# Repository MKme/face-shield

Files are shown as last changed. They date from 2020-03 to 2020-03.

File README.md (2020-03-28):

# face-shield
Open Source Face Shield for Covid-19

### ORIGINAL DESIGN Protective Visor by 3DVerkstan 

 https://www.youmagine.com/designs/protective-visor-by-3dverkstan

<p align="center">
<b>IMPORTANT_ I did not design this from scratch- see orginal design above I just need a place to track my versions and modifications to the files. Original .stl files are found above- split version by TekMason below. Hit @erikcederb on twitter and tell him thanks if you use this too. 

Open source Covid-19 face shield for medical and public use (splash shield NOT mask) reference files tips and tricks I find along the way</b><br>

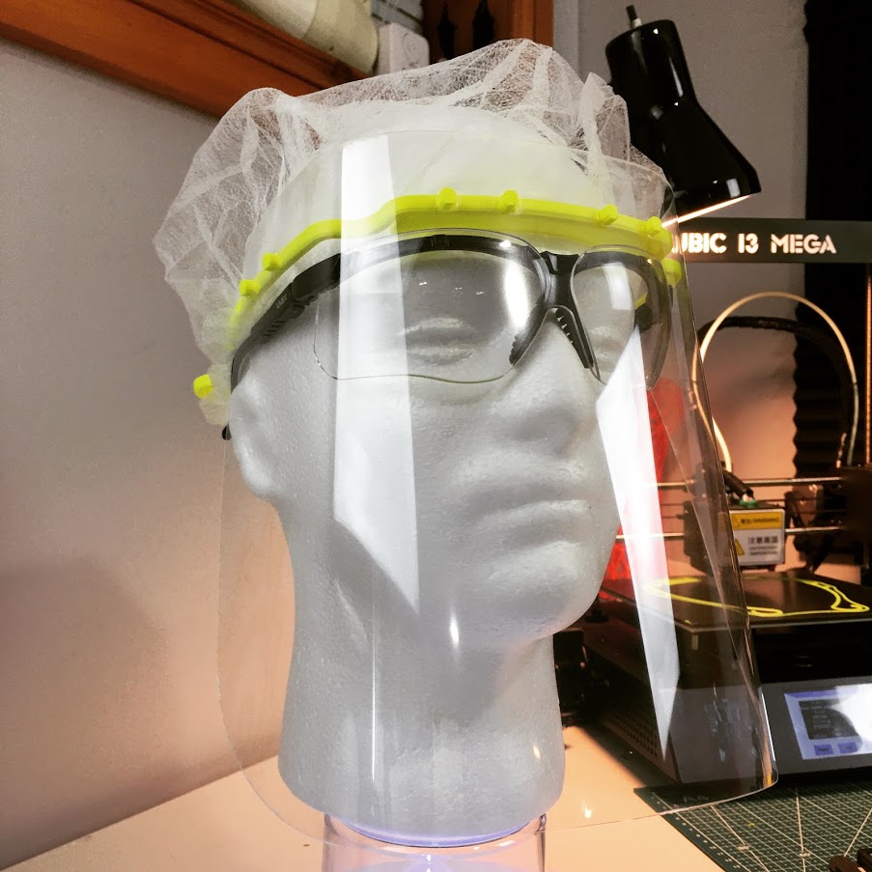
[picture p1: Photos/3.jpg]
 <p align="center">
My Prototype using Visor_frame_v10.stl
  <br>
<br>🐦 <a href="https://twitter.com/mkmeorg">Twitter</a>
| 📺 <a href="https://www.youtube.com/mkmeorg">YouTube</a>
| 🌍 <a href="http://www.mkme.org">mkme.org</a><br>

Support this project and become a patron on <a href="http://mkme.org/patreon">Eric's Patreon</a>.<br>
Website, Forum and store are at http://mkme.org <br>
Chat with Me: <a href="https://discord.gg/j9S4Fgv">Discord</a></b>
</p>

### Overview Video (short):
https://youtu.be/8bWaJXSb-Fw

### FULL Video Tutorial:
https://youtu.be/RJtRBTxELZk

### BUY THE SUPPLIES HERE:

3D Printer (My current fav) :https://amzn.to/2wFEMlt

3D Printer Filament (AMZ3D) https://amzn.to/2vE4upU

Binding Covers (7 mil PVC sheet for shield- Don't laser cut PVC though) https://amzn.to/2Jk5SBt

Acetate Sheets (4.5 mil option): https://amzn.to/2xQYryW

More acetate sheet options: https://amzn.to/3brzXuS

### Version notes:
A4-standard-sheetErics8.5-11- This was first version of full bevels and holes proper for North America paper size

A4-standard-sheetErics8.5-11justholes- This is JUST holes and can be used for someone not wanting to bevel the edges

Letter-sized-shield-for-A4-frame-lasercut .75mm outward from centrebothsides- New version with bevels and holes spaced both sides 0.75mm outboard

Split versions added by Tekmason which can be produced on 3D printers that have smaller build plates
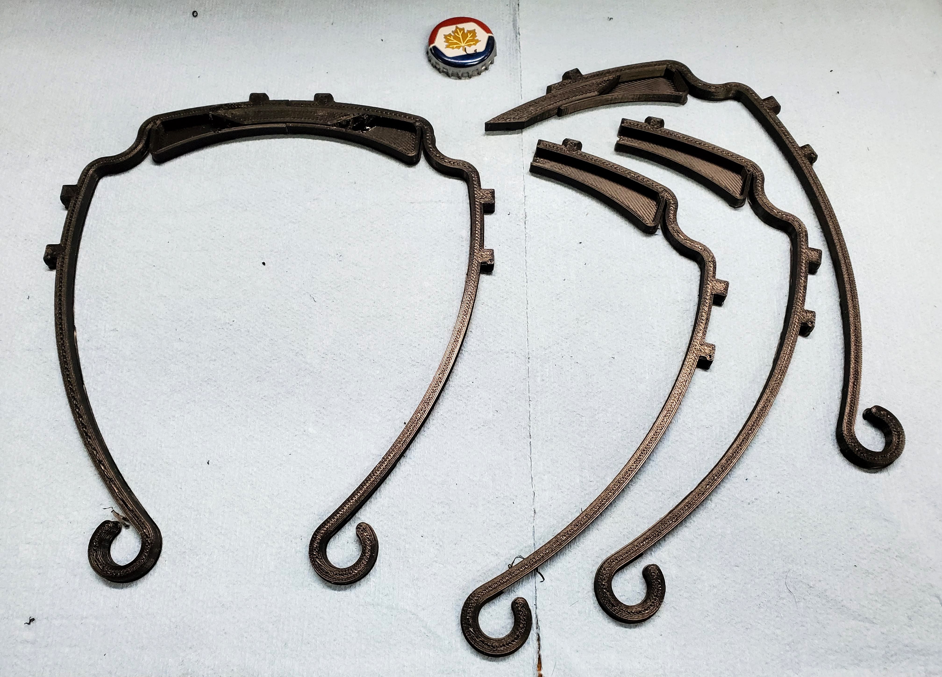
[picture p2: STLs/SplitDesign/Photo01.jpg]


Get the stacked version here from @Carl0sGS so you can print MANY at a time without restarting your printer:
https://github.com/CarlosGS/facemask-print-vertical

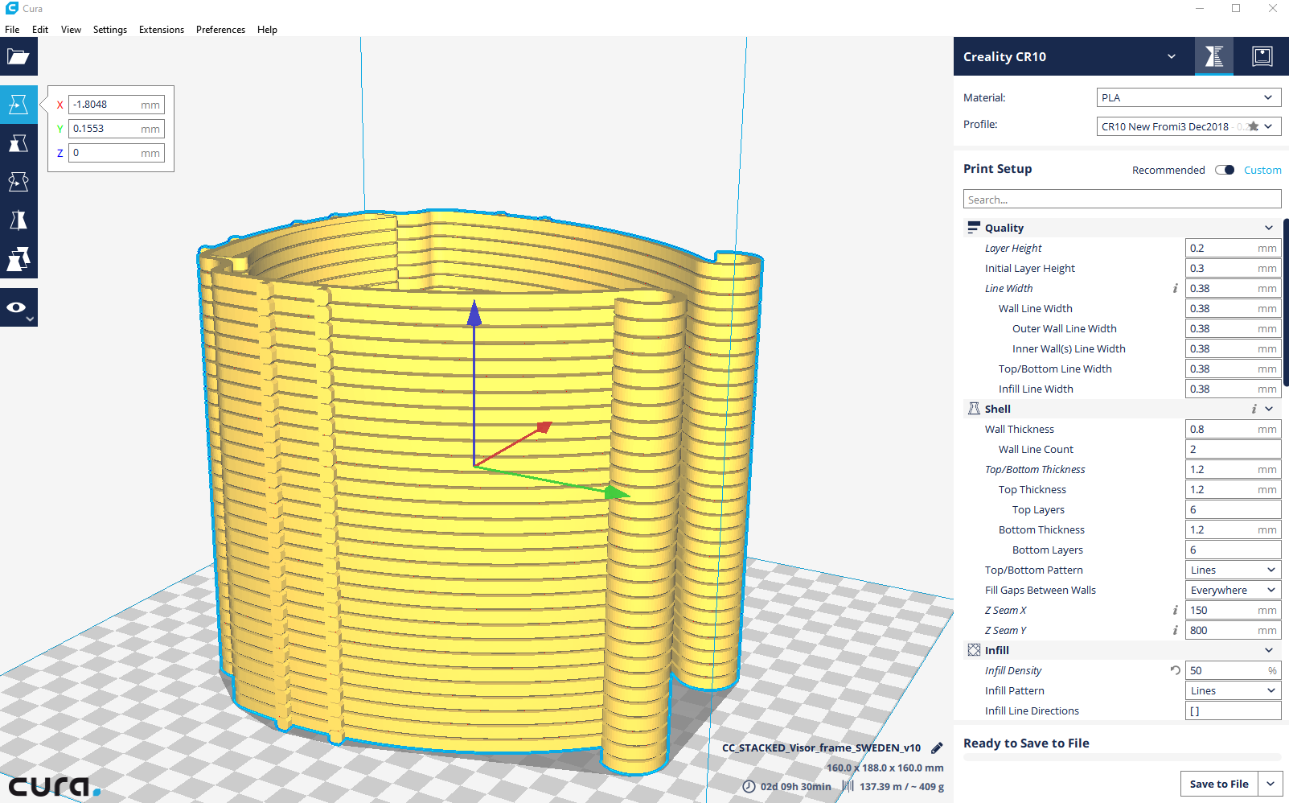
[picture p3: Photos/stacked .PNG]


### Instructions (40 watt lasercutter):

Open my SVG in K40 whisperer and use top section as it was made with version 0.92:

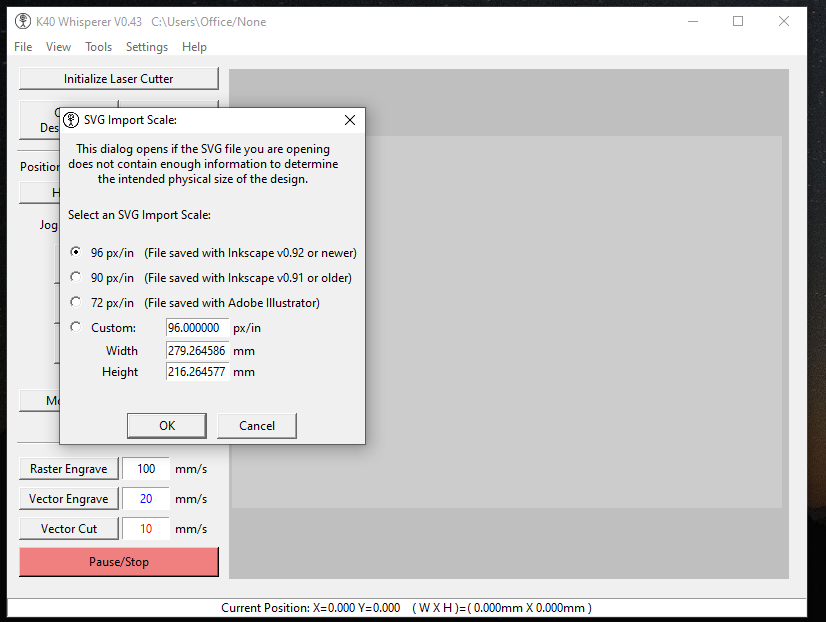
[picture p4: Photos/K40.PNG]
 <p align="center">

I have already done the correct coloration for Vector cut:

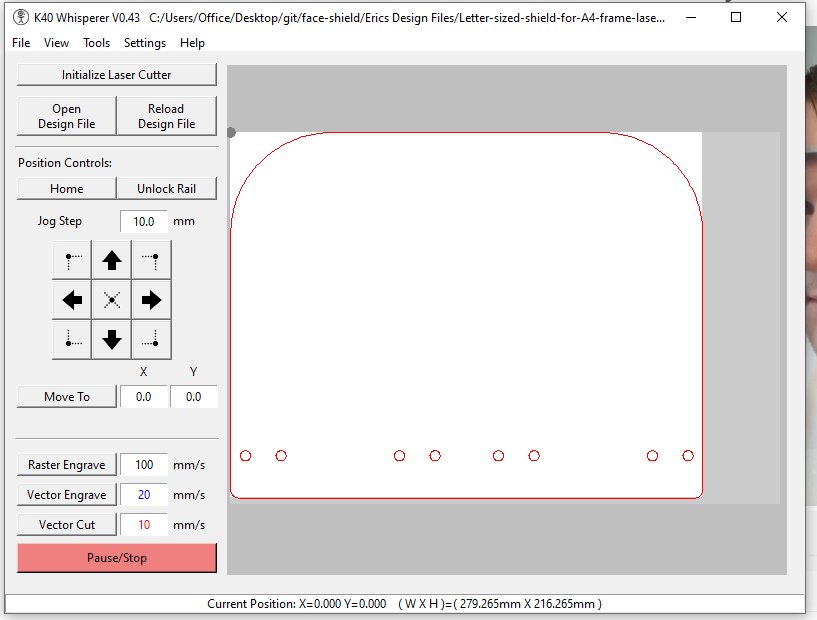
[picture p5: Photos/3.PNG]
 <p align="center">
 
Clcik Vector Cut 

Or use a paper punch and make them manually. 
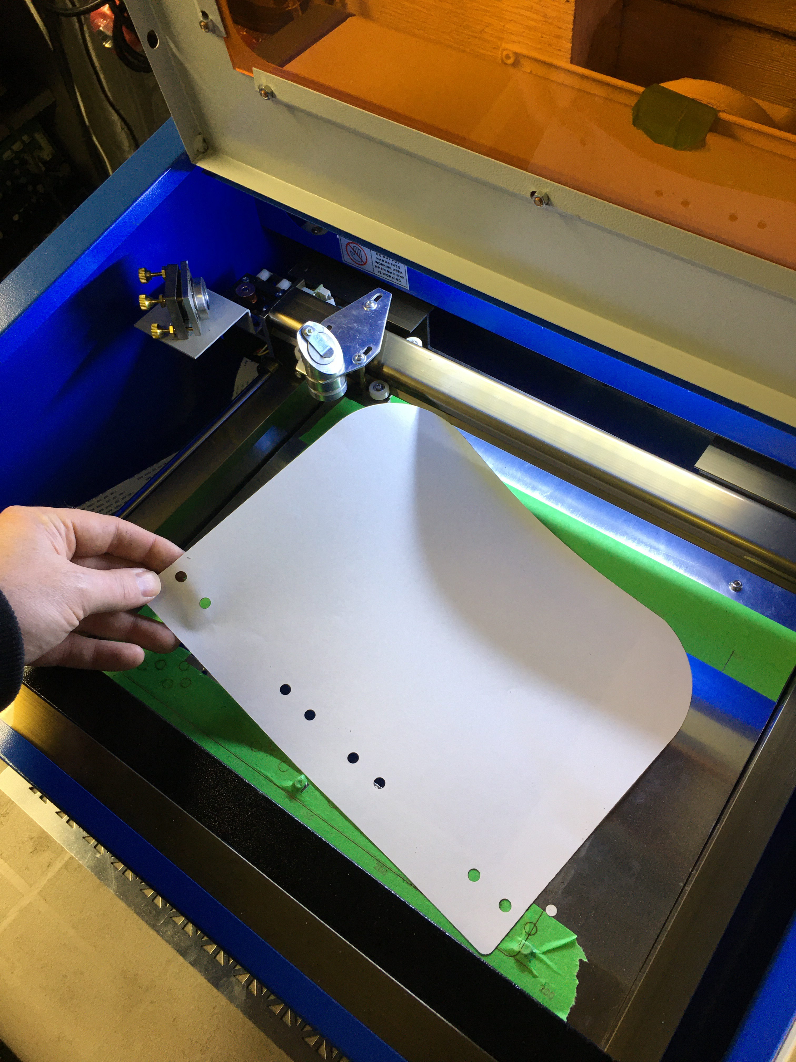
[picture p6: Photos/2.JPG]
<p align="center">

### Disclaimer: 

This design is provided as is without any guarantees or warranty. In association with the product, we make no warranties of any kind, either express or implied, including but not limited to warranties of merchantability, fitness for a particular purpose, of title, or of noninfringement of third party rights. Use of the product by a user is at the user’s risk.

In no event shall MKME Media, nor its directors, employees, partners, agents, suppliers, or affiliates, be liable for any indirect, incidental, special, consequential or punitive damages, including without limitation, loss of profits, data, use, goodwill, or other intangible losses, resulting from (i) your access to or use of or inability to access or use the infomration hosted here or any other upload by MKME Media; (ii) any conduct or content of any third party using the files; (iii) any content obtained from the files; and (iv) unauthorized access, use or alteration of your transmissions or content, whether based on warranty, contract, tort (including negligence) or any other legal theory, whether or not we have been informed of the possibility of such damage, and even if a remedy set forth herein is found to have failed of its essential purpose.

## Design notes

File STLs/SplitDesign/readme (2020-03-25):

These files are derived from Erik Cederberg's original design, Visor Frame North America Letter V3STL at https://www.youmagine.com/designs/protective-visor-by-3dverkstan
These STL files can be produced on 3D printers that have smaller build plates.

Print FaceSheildv3 Split NA(L).stl, FaceSheildv3 Split NA(R).stl and FaceSheildv3 Split NA(J).stl in ABS then use some ABS glue (acetone and ABS mix) to attach the Left and Right sections together with the Joiner.

TekMason

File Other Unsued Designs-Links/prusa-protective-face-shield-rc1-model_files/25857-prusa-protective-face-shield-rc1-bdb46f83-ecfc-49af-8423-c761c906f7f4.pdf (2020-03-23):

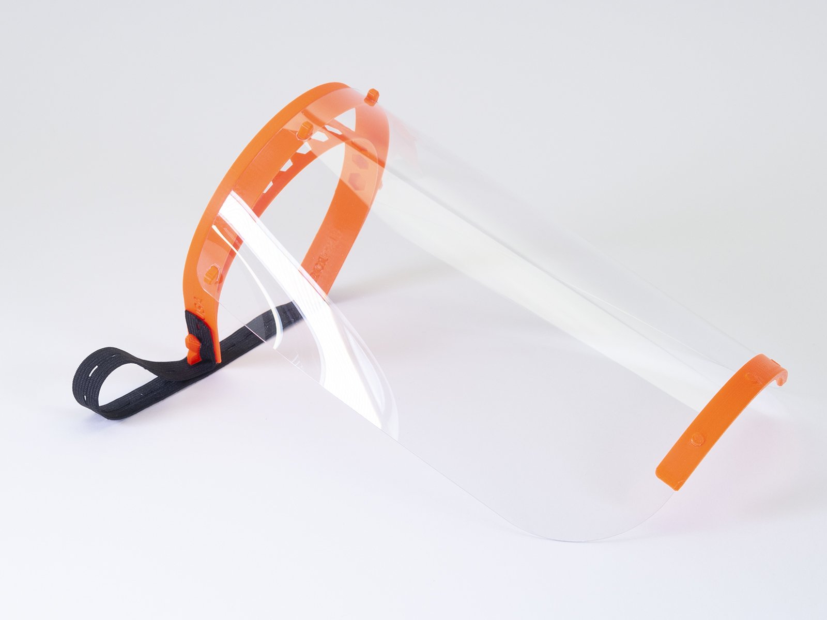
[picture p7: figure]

## Summary

A prototype face shield that we developed. In three days, we went through dozens of prototypes and two verifications with the Czech Ministry of Health.

Version RC1 - pending verification of design

The face shield is still pending validation, right now it is completely safe to make one only for yourself!

Assembly manual: EN: manual.prusa3d.com/Guide/Prusa+Face+Shield/ 1527 CZ: manual.prusa3d.com/Guide/Prusa+Oblicejovy+Stit/1526

Video:

"https://www.youtube.com/embed/pP7z3iw76GA"

Rubber band - you can either use a thicker one and make a hole in it at each end (make at least 10 mm cut) or use a thin one and tie it to both ends of the shield.

Front plate material - we used 0.5 mm thick petg sheet (Covestro VIVAK), but you should be able to use any clear laser cuttable plastic with similar thickness.

Licence and selling of face shields We share these files under noncommerical licence. It would be great if you donated these shields to those in need for free. If you need to cover your production costs, we are ok with

Prusa Research (https://www.prusaprinters.org/social/16/prints)

## Prusa Protective Face Shield - RC1

VIEW IN BROWSER (https://www.prusaprinters.org/prints/25857-prusa-protective-face-shield-rc1)

updated 20. 3. 2020 | published 18. 3. 2020

2.01 hrs

1 pcs

f

0.25 mm

k

0.40 mm

h

8

32.00 g

d

MK3/S

Print Files (.gcode) | DOWNLOAD ALL FILES (https://www.prusaprinters.org/prints/25857-prusa-protective-face-shield-rc1/files)

4.2 MB

- 2.01 hrs f 0.25 mm k 0.40 mm h PET | 32.20 g d MK3/S
updated 18. 3. 2020 | (https://www.prusaprinters.org/prints/25857-prusa-protective-face-shield-rc1/files)
Model Files (.stl, .3mf, .obj, .amf) | DOWNLOAD ALL FILES (https://www.prusaprinters.org/prints/25857-prusa-protective-face-shield-rc1/files)

284.2 KB
updated 18. 3. 2020 | (https://www.prusaprinters.org/prints/25857-prusa-protective-face-shield-rc1/files)

383.1 KB
updated 18. 3. 2020 | (https://www.prusaprinters.org/prints/25857-prusa-protective-face-shield-rc1/files)

585.1 KB
updated 18. 3. 2020 | (https://www.prusaprinters.org/prints/25857-prusa-protective-face-shield-rc1/files)

you selling the shields for production cost. However, we do not want to see these shields on eBay for $500.

More information: https://blog.prusaprinters.org/from-design-tomass-3d-printing-of-medical-shields-in-three-days/ (https://blog.prusaprinters.org/from-design-to-mass-3d-printing-of-medical-shields-in-three-days/)

Healthcare (https://www.prusaprinters.org/prints?categoryId=87) > Accessibility (https://www.prusaprinters.org/prints?categoryId=88)

Supports are not necessary. Print with at least 3 perimeters, about 30% infill.

Ideally, print it from PETG.

covid19-shield_025mm_petg_mk3s_2h1m.gcode

covid19-shield.3mf

bottom_reinforcement.stl

covid19_shield_r1.stl

3.9 KB
updated 18. 3. 2020 | (https://www.prusaprinters.org/prints/25857-prusa-protective-face-shield-rc1/files)

52.6 KB
updated 20. 3. 2020 | (https://www.prusaprinters.org/prints/25857-prusa-protective-face-shield-rc1/files)

## License

This work is licensed under a
Creative Commons (4.0 International License)

Attribution-NonCommercial (http://creativecommons.org/licenses/by-nc/4.0/)

✖ | Sharing without ATTRIBUTION
✔ | Remix Culture allowed
✖ | Commercial Use
✖ | Free Cultural Works
✖ | Meets Open Definition

shield_final.dxf

shield_longer_version.stp

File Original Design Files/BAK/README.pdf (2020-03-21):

# Protective Visor by 3DVerkstan

### By: (erikcederb) License: Commercial use is allowed, you must attribute the creator, you may remix this

work and the remixed work should be made available under this license.

### Published on: Mar 21, 2020 Located at: http://www.youmagine.com/designs/protective-visor-by-3dverkstan Short description:

Protective visor optimized for fast FDM printing

### Description:

Since the medical community currently (2020-03-20) has a urgent need for protective visors and other PPE for our heroes that spends their days battling COVID-19, myself and my co-workers at 3DVerkstan have spent a lot of time during the past few days designing a printable visor. This in a WORK IN PROGRESS, and might get multiple revisions during the coming days/weeks, but this first released version is the first one on its way to be tried out by a local hospital. The design goals included: * Using readily available plastic sheets with as little modification as possible, and only common tools used. * All features printable with nozzle sizes up to 1mm and layer heights up to 0.5mm * Drip protection above the eyes * Printable in less than 20 minutes * No tight tolerances requiring well-tuned printers. * Design that works equally well with most common materials (PLA, CPE, PETG, ABS etc.) The plastic shield can be made out of any semi-stiff plastic sheet between 0.1 and 1mm, including overhead film, cover sheets for binding machines etc, as long as it is available in A4 format (or letter format for the dedicated version). The holes for mounting the plastic sheets are made with a Swedishstyle hole punch, set to A6 format and punched two times on one of the long sides of each sheet to make a total of 8 holes. (https://en.wikipedia.org/wiki/Hole_punch#Sweden) I also got requests for a dedicated version to be used with Letter sized plastic sheets and the north american 3-hole system punches. This version is currently NOT TESTED, and might need some adjustment. If you try it out, please reach out to me on Twitter @erikcederb so i can update these files accordingly. If you need it to sit tighter on your head or if you are leaning over patients a lot and worry about it falling off, a simple rubber band can be put over the two hooks in the back.

If you can, please use the online documentation found at http://www.youmagine.com/designs/protective-visorby-3dverkstan because those may have been been updated. Also, there you can interact and provide praise and/or feedback.

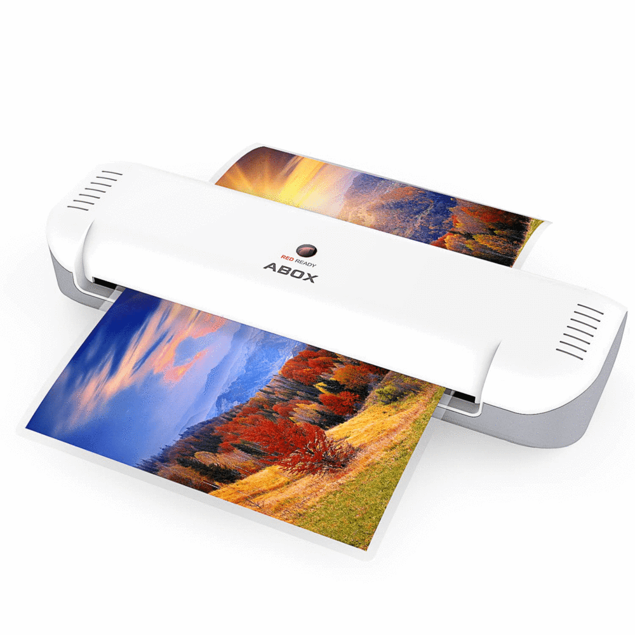
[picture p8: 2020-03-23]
Other Unsued Designs-Links/home-health-abox-a4-thermal-laminator-6643976470601_1000x1000.png

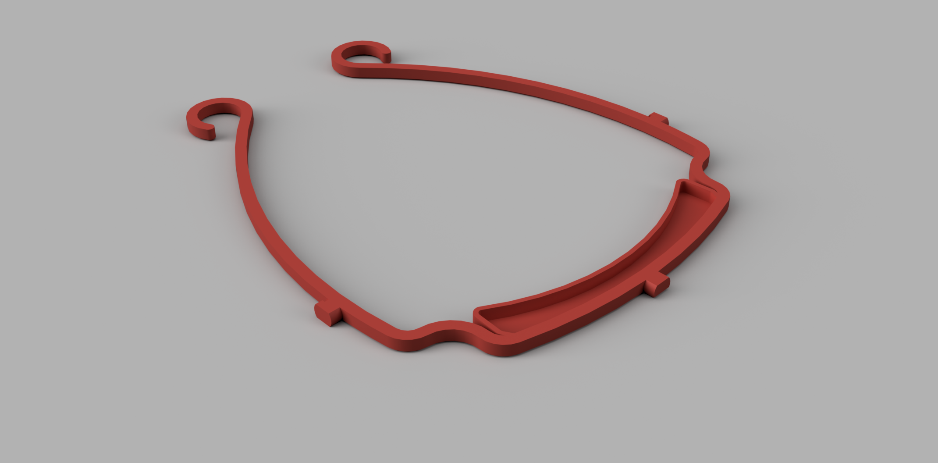
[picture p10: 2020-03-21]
Original Design Files/BAK/Visor_frame_letter_version_v2.png

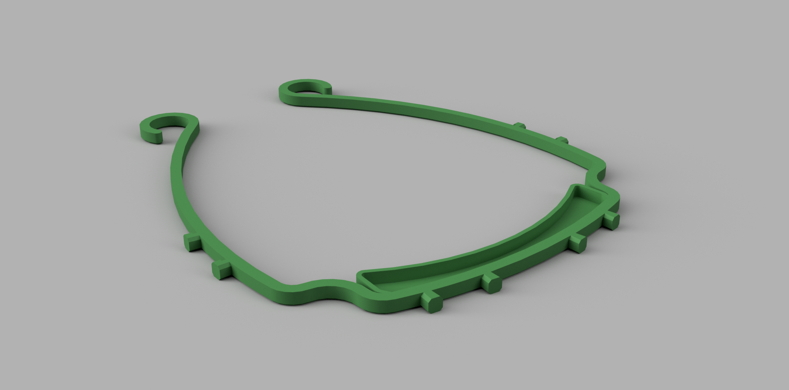
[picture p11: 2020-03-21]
Original Design Files/BAK/Visor_frame_dual_a6_holes_v3.png

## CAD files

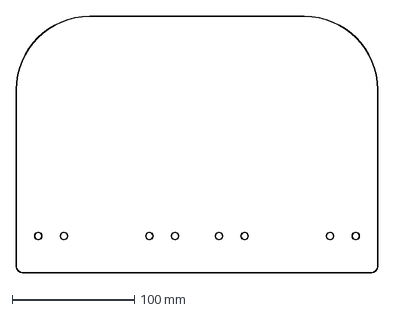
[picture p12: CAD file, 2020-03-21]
Original Design Files/BAK/Facesheet.dxf
296.0 x 210.0 mm

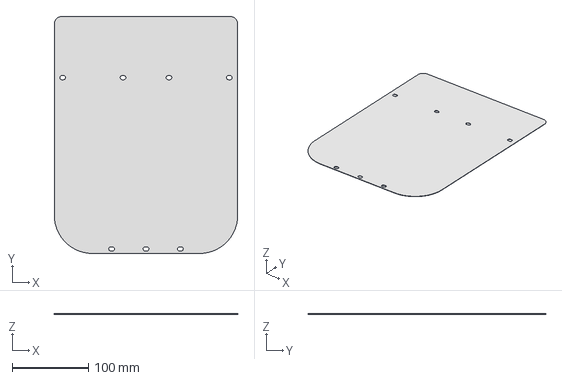
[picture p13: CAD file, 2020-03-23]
Other Unsued Designs-Links/prusa-protective-face-shield-rc1-model_files/shield_longer_version.stp
240.0 x 310.0 x 0.5 mm

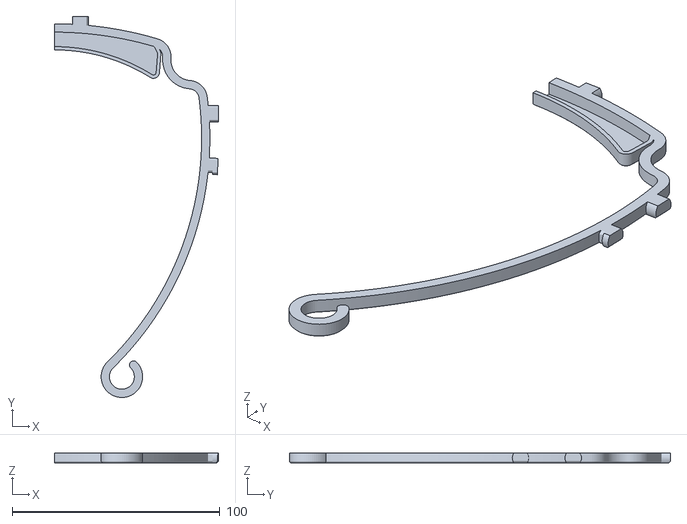
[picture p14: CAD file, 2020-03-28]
STLs/SplitDesign/FaceSheildv5 Split NA(R).stl
79.3 x 183.6 x 5.00

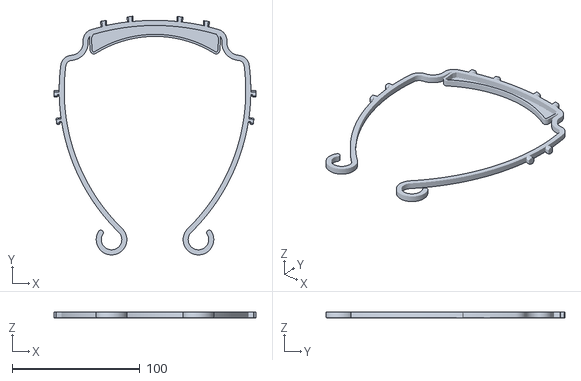
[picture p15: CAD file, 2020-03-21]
Original Design Files/BAK/Visor_frame_v10.stl
158.0 x 186.9 x 5.00

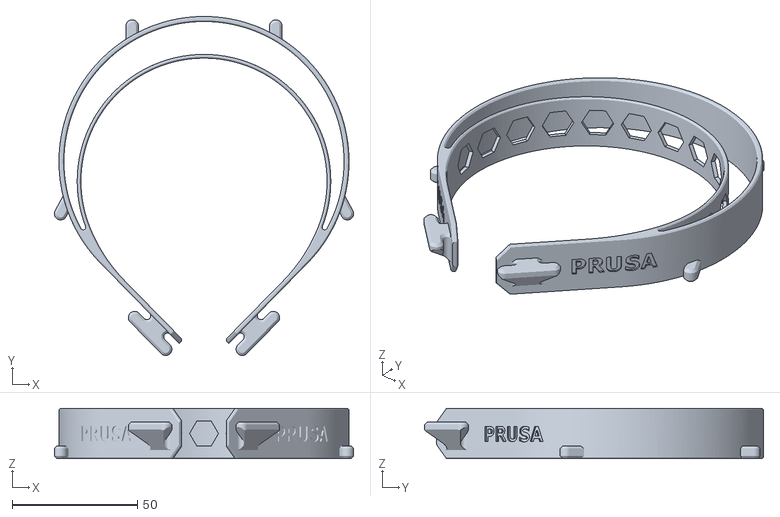
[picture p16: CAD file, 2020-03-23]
Other Unsued Designs-Links/prusa-protective-face-shield-rc1-model_files/covid19_shield_r1.stl
119.7 x 135.6 x 20.0

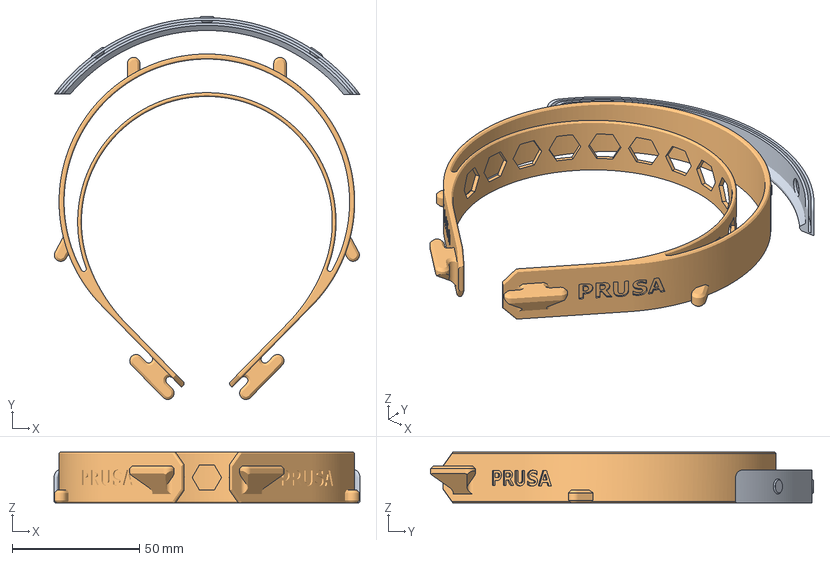
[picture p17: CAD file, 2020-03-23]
Other Unsued Designs-Links/prusa-protective-face-shield-rc1-model_files/covid19-shield.3mf
120.1 x 150.3 x 20.0 mm
reinforcement_final.stl
COVID19_SHILED_R1 (1).stl

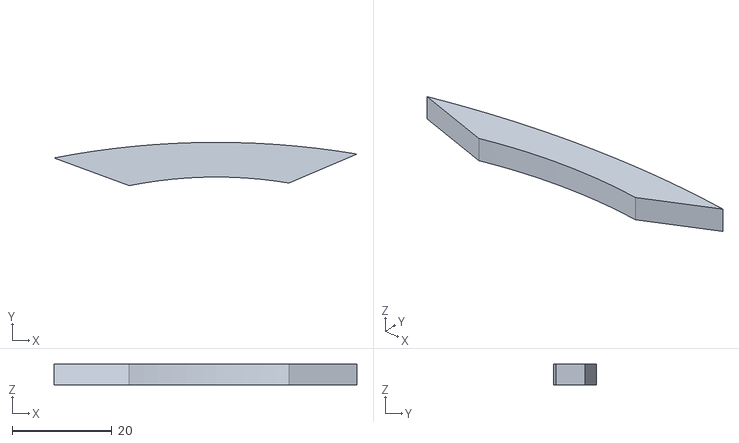
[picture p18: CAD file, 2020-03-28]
STLs/SplitDesign/FaceSheildv5 Split NA(J).stl
60.8 x 8.70 x 4.20

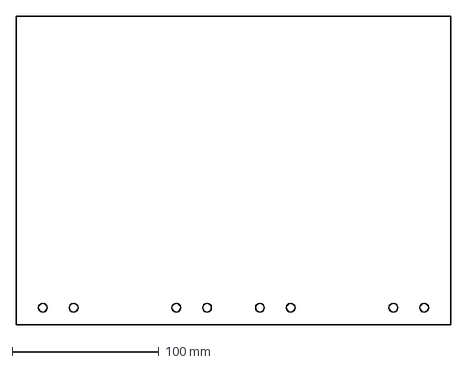
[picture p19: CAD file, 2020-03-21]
Original Design Files/BAK/A4-standard-sheet.dxf
296.0 x 210.0 mm

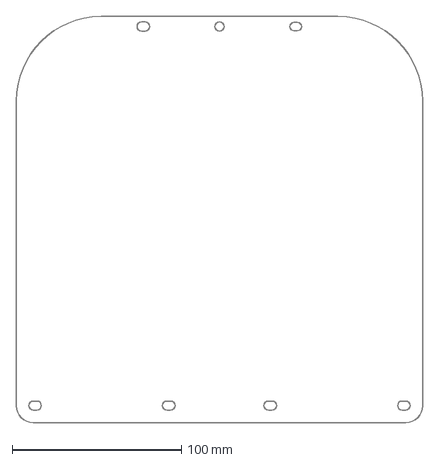
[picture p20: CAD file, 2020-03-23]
Other Unsued Designs-Links/prusa-protective-face-shield-rc1-model_files/shield_final.dxf
240.0 x 240.0 mm

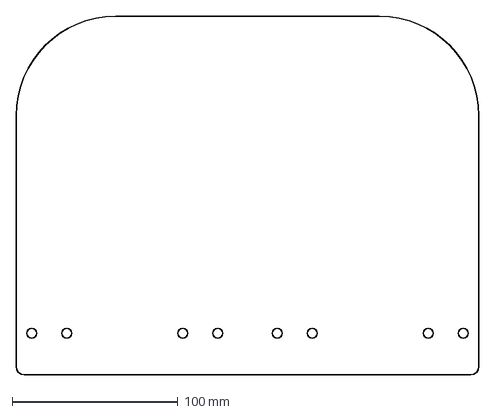
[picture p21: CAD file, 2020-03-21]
Original Design Files/BAK/Letter-sized-shield-for-A4-frame-lasercut.dxf
279.0 x 216.0 mm

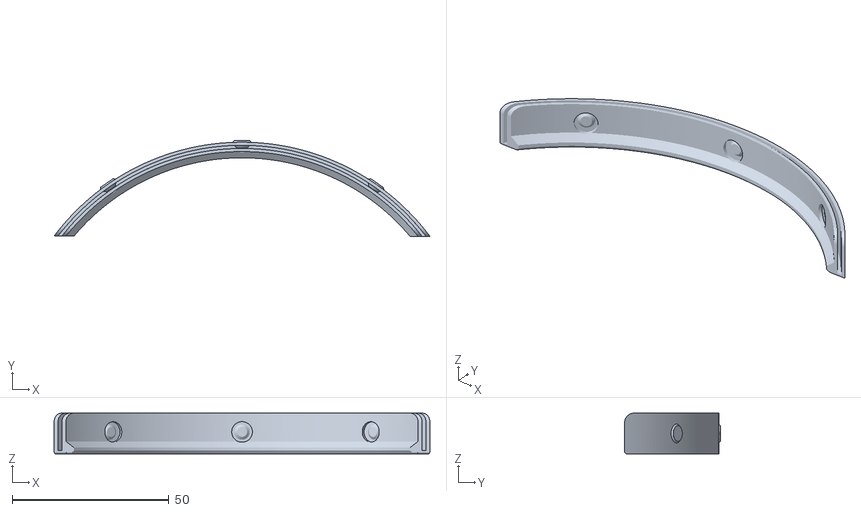
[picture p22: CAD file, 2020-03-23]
Other Unsued Designs-Links/prusa-protective-face-shield-rc1-model_files/bottom_reinforcement.stl
120.1 x 30.6 x 13.0

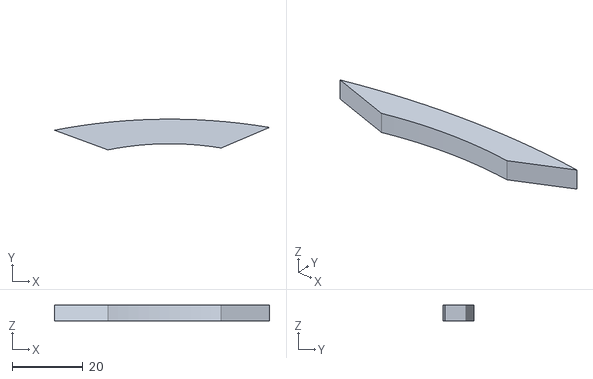
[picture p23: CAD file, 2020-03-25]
STLs/SplitDesign/FaceSheildv3 Split NA(J).stl
60.8 x 8.70 x 4.50

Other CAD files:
STLs/SplitDesign/FaceSheildv5 Split NA(L).stl
Original Design Files/BAK/Visor_Frame_Letter_v1.stl
STLs/SplitDesign/FaceSheildv3 Split NA(R).stl
STLs/SplitDesign/FaceSheildv3 Split NA(L).stl
STLs/SplitDesign/OLD/FaceSheildv3 Split NA(R).stl
STLs/SplitDesign/OLD/FaceSheildv3 Split NA(L).stl

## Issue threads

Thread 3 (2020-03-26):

Right Frame STL is the Wrong File

TekMason, 2020-03-26:
FaceSheildv3 Split NA(R).stl was the same as FaceSheildv3 Split NA(L).stl

Replaced the Right Frame file with the correct one in [Pull Request #2 - Replaced the Right Frame](https://github.com/MKme/face-shield/pull/2)

TekMason

MKme, 2020-03-26:
Merged

Closed 2020-03-26.

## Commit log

2020-03-21 Removed orginals
    [A4-standard-sheet.dxf, Facesheet.dxf, Letter-sized-shield-for-A4-frame-lasercut.dxf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]
2020-03-23 Other Links Added
    [bottom_reinforcement.stl, covid19-shield.3mf, covid19_shield_r1.stl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]
2020-03-26 Updated Right Side File
    The proper Right frame
    [FaceSheildv3 Split NA(R).stl]
2020-03-28 Split in OpenSCAD
    v5 STL files can now be stacked with CarlosGS's stacking code at https://github.com/CarlosGS/facemask-print-vertical/tree/master/source_code/generic_stacker
    Previous STLs were split in Fusion360 and the STL exports from there were not consistent and they could not be stacked in OpenSCAD with GCAL assertion violation errors
    [FaceSheildv5 Split NA(J).stl, FaceSheildv5 Split NA(L).stl, FaceSheildv5 Split NA(R).stl]
2020-03-28 Split in Fusion360
    Inconsistent files that cannot be stacked in OpenSCAD
    [FaceSheildv3 Split NA(J).stl, FaceSheildv3 Split NA(L).stl, FaceSheildv3 Split NA(R).stl]
